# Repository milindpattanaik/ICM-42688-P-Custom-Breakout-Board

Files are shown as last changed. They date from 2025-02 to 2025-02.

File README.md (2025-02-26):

# ICM-42688-P Breakout Board

## Overview

### What is the ICM-42688-P?
The **ICM-42688-P** is a high-performance **6-axis Inertial Measurement Unit (IMU)** that integrates a **3-axis gyroscope** and a **3-axis accelerometer** in a compact package. It offers **low noise, high stability, and precision motion tracking**, making it ideal for applications like **drones, robotics, and industrial motion sensing**.  

The sensor supports both **I2C and SPI** communication, features **programmable digital filters, FIFO buffering, and low power consumption**, and includes **two interrupt pins** for efficient data handling. Its **temperature stability and low drift** make it well-suited for demanding applications requiring **accurate inertial measurements**.

### About This Project
This project is a **custom breakout board** for the ICM-42688-P, designed using **KiCad 8.0**. It includes:
- **Hardware**: A compact PCB with **I2C & SPI support**, onboard **3.3V LDO**, and **interrupt pins**.
- **Firmware**: Example code using **PlatformIO (Arduino framework)** for easy testing.
- **Testing Guide**: Steps to set up and read sensor data over I2C & SPI.

The driver used for interfacing with the **ICM-42688-P** is an open-source implementation developed by [Inhwan Wee ](https://github.com/finani) and is hosted on [https://github.com/finani/ICM42688](https://github.com/finani/ICM42688). This driver provides a well-structured and efficient way to communicate with the sensor over I2C or SPI, enabling seamless integration with Arduino and PlatformIO environments.

## Hardware Design
### Features:
- **Power Supply**: 3.3V LDO regulator onboard
- **Communication**: Supports both **I2C (SDA/SCL)** and **SPI (SCK, SDI, SDO, CS)**
- **Interrupts**: `INT1` and `INT2` available
- **Jumpers**: Select between I2C and SPI modes
- **Designed in**: KiCad 8.0
- **Tested on**: PlatformIO with Arduino framework

### Schematic
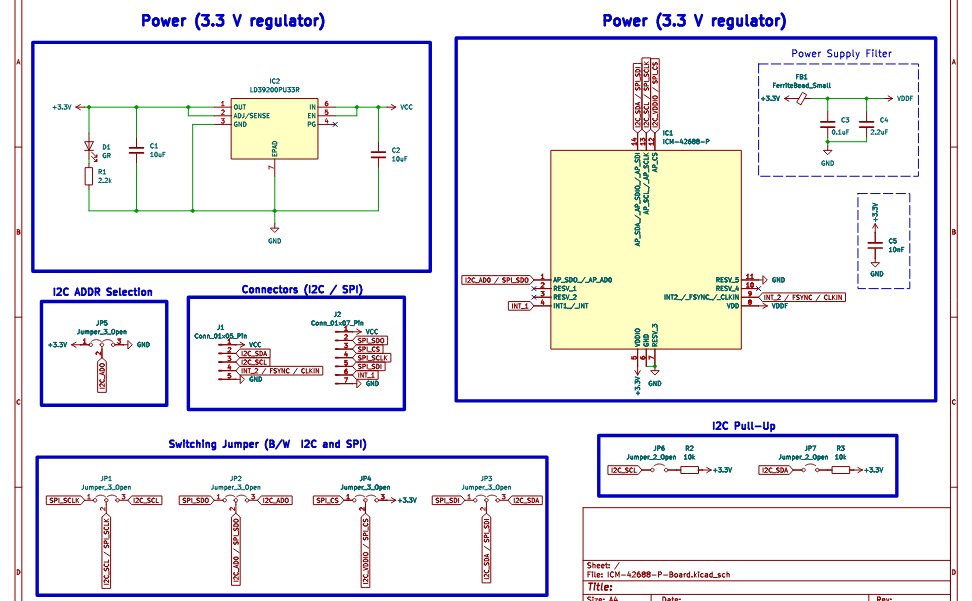
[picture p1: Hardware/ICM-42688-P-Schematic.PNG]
ICM-42688-P Schematic


### PCB Layout
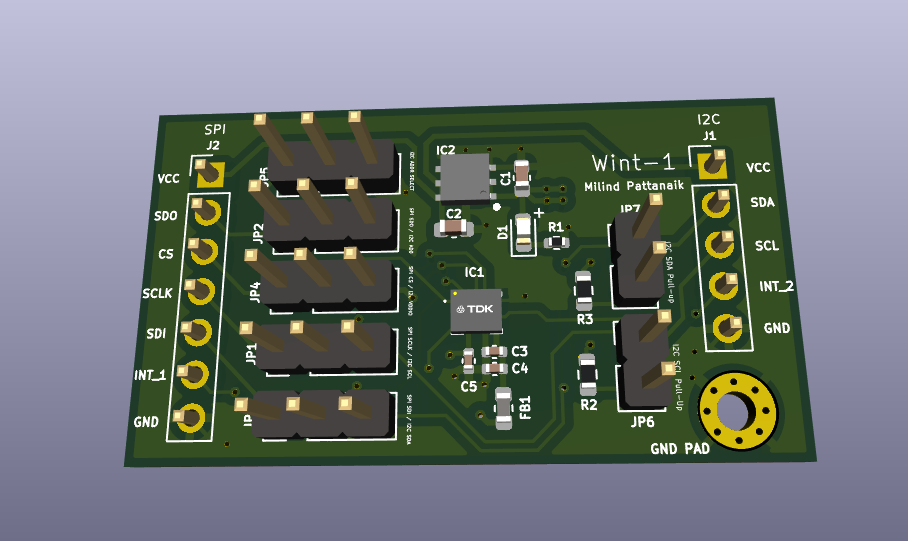
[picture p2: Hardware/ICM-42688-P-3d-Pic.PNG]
ICM-42688-P PCB


## Software

### Fixing `<cstdint>` Issues with AVR-GCC  

When compiling for AVR-based boards (e.g., **Arduino Uno, Mega, etc.**) using **AVR-GCC**, you may encounter the following error:  

```sh
fatal error: cstdint: No such file or directory
```

This happens because **AVR-GCC does not fully support C++ standard headers like `<cstdint>`**. This is a common defect in the arduino library.  

### Solution: Use `<stdint.h>` Instead  
The best solution is to replace `<cstdint>` with `<stdint.h>` in the `registers.h` file of the driver src code.  

❌ **Incorrect:**  
```cpp
#include <cstdint>  // This may cause issues with AVR-GCC
```
✅ **Correct:**  
```cpp
#ifdef AVR  // If compiling for AVR, define NO_CSTDINT to prevent including <cstdint>
# define NO_CSTDINT 1
#endif

// If NO_CSTDINT is NOT defined, include the standard C++ <cstdint>
#ifndef NO_CSTDINT
# include <cstdint>
#else
# include <stdint.h>

// If <cstdint> is unavailable, manually provide the needed types.
namespace std {
  using ::int8_t;           
  using ::uint8_t;         
                     
  using ::int16_t;         
  using ::uint16_t;       
                     
  using ::int32_t;         
  using ::uint32_t;       
}

#endif
```
✅ `<stdint.h>` is the **C version of `<cstdint>`** and is fully compatible with AVR-GCC.

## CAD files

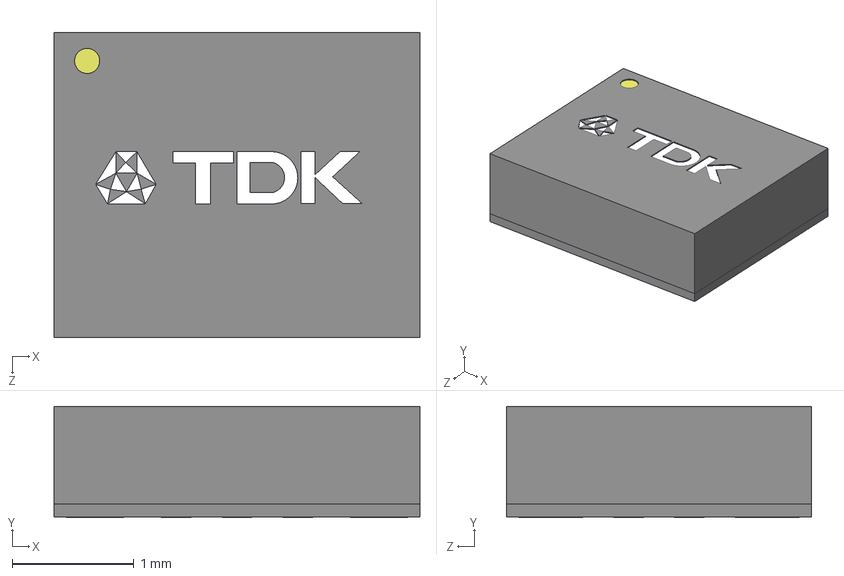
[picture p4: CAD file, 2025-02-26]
Hardware/3dmodels/ICM-42688-P.stp
3.00 x 0.91 x 2.50 mm

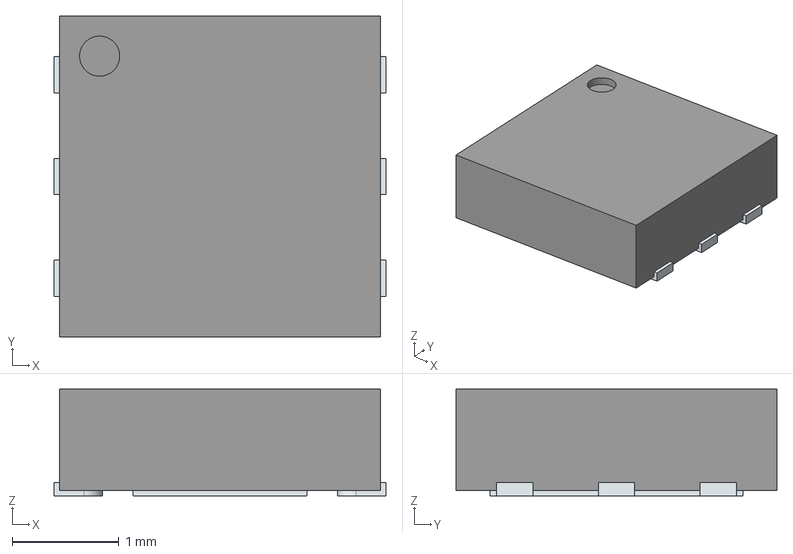
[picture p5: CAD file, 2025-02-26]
Hardware/3dmodels/LD39200PU33R.stp
3.10 x 3.00 x 1.00 mm
ThermalPin
PinsArrayLR

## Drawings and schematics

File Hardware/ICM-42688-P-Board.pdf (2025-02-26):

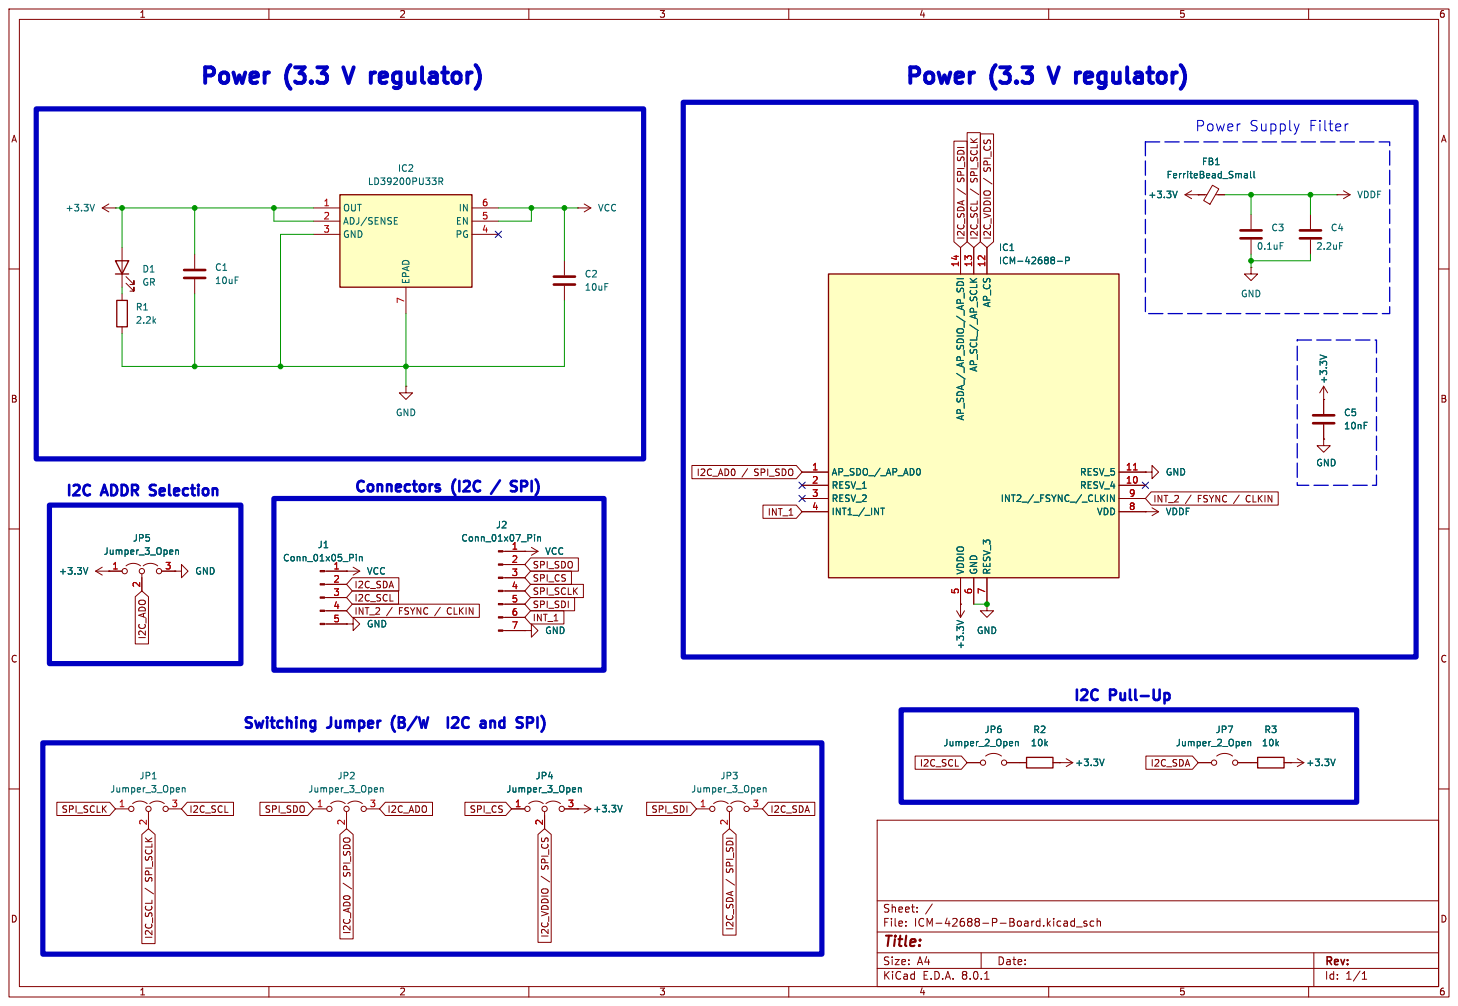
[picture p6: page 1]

Jumper_3_Open
Id: 1/1 Title: File: ICM-42688-P-Board.kicad_sch Sheet: / 1

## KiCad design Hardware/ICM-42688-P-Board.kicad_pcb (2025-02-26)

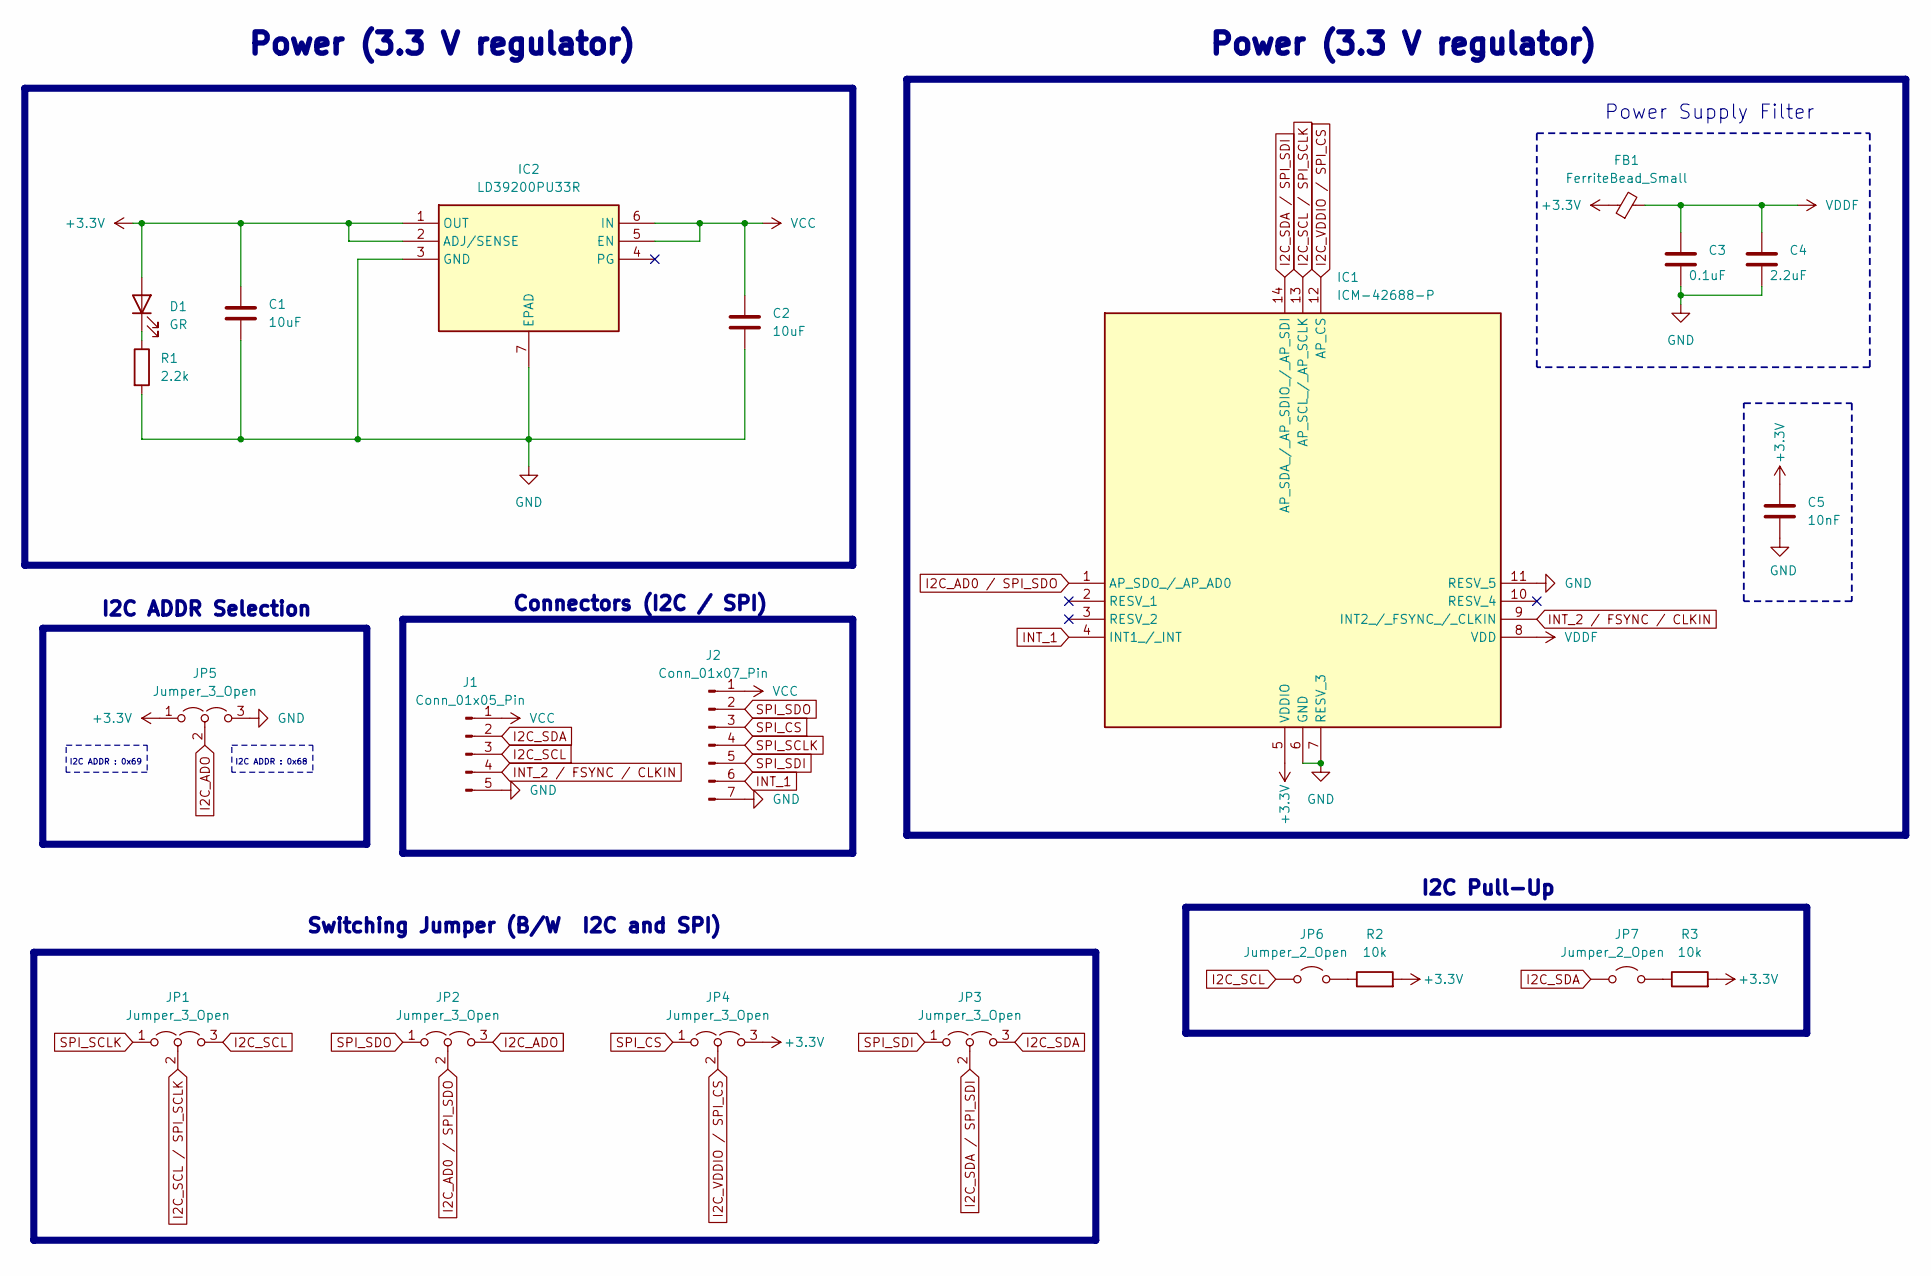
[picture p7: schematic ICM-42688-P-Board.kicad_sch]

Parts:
C1, C2: 10uF; C_0603_1608Metric
C3: 0.1uF; C_0402_1005Metric
C4: 2.2uF; C_0402_1005Metric
C5: 10nF; C_0402_1005Metric
D1: GR; LED_0603_1608Metric
FB1: FerriteBead_Small; L_0603_1608Metric
IC1: ICM-42688-P; IIM42352; Mouser Part Number 410-ICM-42688-P
IC2: LD39200PU33R; SON95P300X300X100-7N-D; Mouser Part Number 511-LD39200PU33R
J1: Conn_01x05_Pin; PinHeader_1x05_P2.54mm_Vertical
J2: Conn_01x07_Pin; PinHeader_1x07_P2.54mm_Vertical
JP1, JP2, JP3, JP4, JP5: Jumper_3_Open; PinHeader_1x03_P2.54mm_Vertical
JP6, JP7: Jumper_2_Open; PinHeader_1x02_P2.54mm_Vertical
R1: 2.2k; R_0402_1005Metric
R2, R3: 10k; R_0603_1608Metric

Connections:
+3.3V: C1.1, C5.1, D1.2 (A), FB1.1, IC1.5 (VDDIO), IC2.1 (OUT), IC2.2 (ADJ/SENSE), JP4.3 (B), JP5.1 (A), R2.2, R3.2
GND: C1.2, C2.2, C3.2, C4.2, C5.2, IC1.6 (GND), IC1.7 (RESV_3), IC1.11 (RESV_5), IC2.3 (GND), IC2.7 (EPAD), J1.5, J2.7, JP5.3 (B), R1.2; also elsewhere on the board
I2C_AD0 / SPI_SDO: IC1.1 (AP_SDO_/_AP_AD0), JP2.2 (C)
I2C_ADO: JP2.3 (B), JP5.2 (C)
I2C_SCL: J1.3, JP1.3 (B), JP6.1 (A)
I2C_SCL / SPI_SCLK: IC1.13 (AP_SCL_/_AP_SCLK), JP1.2 (C)
I2C_SDA: J1.2, JP3.3 (B), JP7.1 (A)
I2C_SDA / SPI_SDI: IC1.14 (AP_SDA_/_AP_SDIO_/_AP_SDI), JP3.2 (C)
I2C_VDDIO / SPI_CS: IC1.12 (AP_CS), JP4.2 (C)
INT_1: IC1.4 (INT1_/_INT), J2.6
INT_2 / FSYNC / CLKIN: IC1.9 (INT2_/_FSYNC_/_CLKIN), J1.4
unnamed: D1.1 (K), R1.1
unnamed: JP6.2 (B), R2.1
unnamed: JP7.2 (B), R3.1
SPI_CS: J2.3, JP4.1 (A)
SPI_SCLK: J2.4, JP1.1 (A)
SPI_SDI: J2.5, JP3.1 (A)
SPI_SDO: J2.2, JP2.1 (A)
VCC: C2.1, IC2.5 (EN), IC2.6 (IN), J1.1, J2.1
VDDF: C3.1, C4.1, FB1.2, IC1.8 (VDD)

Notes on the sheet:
Power Supply Filter
I2C ADDR : 0x69
I2C Pull-Up
I2C ADDR Selection
Power (3.3 V regulator)
Connectors (I2C / SPI)
I2C ADDR : 0x68
Switching Jumper (B/W I2C and SPI)

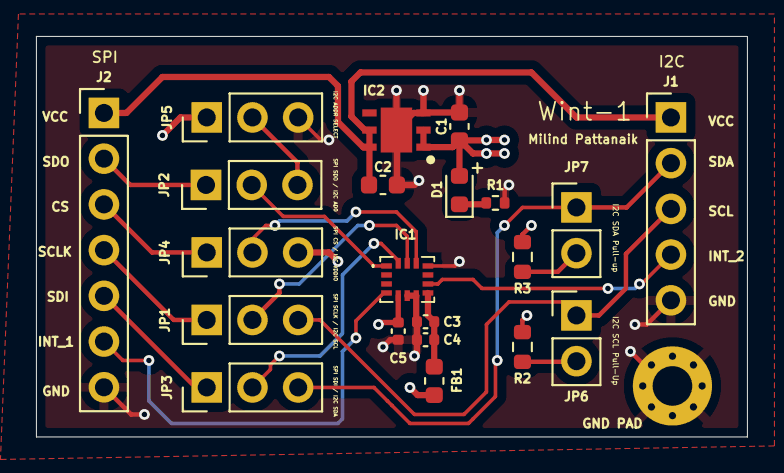
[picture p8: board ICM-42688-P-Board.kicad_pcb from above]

Board: 4 copper layers, 39.5 x 22.2 mm, 22 parts (0 on the bottom side), 20 nets.

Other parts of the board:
GND PAD: MountingHole_2.2mm_M2_Pad_Via

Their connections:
GND: GND PAD.1; also elsewhere on the board

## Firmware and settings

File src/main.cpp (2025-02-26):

#include <Arduino.h>
#include "ICM42688.h"

// I2C Implementation

// an ICM42688 object with the ICM42688 sensor on I2C bus 0 with address 0x68
ICM42688 IMU(Wire, 0x68);

void setup() {
  // serial to display data
  Serial.begin(115200);
  while(!Serial) {}

  // start communication with IMU
  int status = IMU.begin();
  if (status < 0) {
    Serial.println("IMU initialization unsuccessful");
    Serial.println("Check IMU wiring or try cycling power");
    Serial.print("Status: ");
    Serial.println(status);
    while(1) {}
  }
  Serial.println("ax,ay,az,gx,gy,gz,temp_C");
}

void loop() {
  // read the sensor
  IMU.getAGT();
  // display the data
  Serial.print(IMU.accX(),6);
  Serial.print("\t");
  Serial.print(IMU.accY(),6);
  Serial.print("\t");
  Serial.print(IMU.accZ(),6);
  Serial.print("\t");
  Serial.print(IMU.gyrX(),6);
  Serial.print("\t");
  Serial.print(IMU.gyrY(),6);
  Serial.print("\t");
  Serial.print(IMU.gyrZ(),6);
  Serial.print("\t");
  Serial.println(IMU.temp(),6);
  delay(100);
}

// SPI Implementation

// // an ICM42688 object with the ICM42688 sensor on SPI bus 0 and chip select pin 10
// ICM42688 IMU(SPI, 10);

// void setup() {
//   // serial to display data
//   Serial.begin(115200);
//   while(!Serial) {}

//   // start communication with IMU
//   int status = IMU.begin();
//   if (status < 0) {
//     Serial.println("IMU initialization unsuccessful");
//     Serial.println("Check IMU wiring or try cycling power");
//     Serial.print("Status: ");
//     Serial.println(status);
//     while(1) {}
//   }
//   Serial.println("ax,ay,az,gx,gy,gz,temp_C");
// }

// void loop() {
//   // read the sensor
//   IMU.getAGT();
//   // display the data
//   Serial.print(IMU.accX(),6);
//   Serial.print("\t");
//   Serial.print(IMU.accY(),6);
//   Serial.print("\t");
//   Serial.print(IMU.accZ(),6);
//   Serial.print("\t");
//   Serial.print(IMU.gyrX(),6);
//   Serial.print("\t");
//   Serial.print(IMU.gyrY(),6);
//   Serial.print("\t");
//   Serial.print(IMU.gyrZ(),6);
//   Serial.print("\t");
//   Serial.println(IMU.temp(),6);
//   delay(100);
// }

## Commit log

2025-02-26 feat: add ICM-42688-P-Custom-Breakout-Board project
    add the ICM-42688-P-Custom-Breakout-Board Project which includes the hardware and arduino software to test
    [ICM-42688-P-Board.kicad_pcb, ICM-42688-P-Board.kicad_sch, ICM-42688-P.stp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]
2025-02-26 feat: add SPI code
    add SPI code for ICM-42688-P
